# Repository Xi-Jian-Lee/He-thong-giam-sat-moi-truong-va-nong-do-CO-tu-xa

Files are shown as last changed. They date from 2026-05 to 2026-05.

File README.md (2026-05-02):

Tên đề tài: Nghiên cứu, thiết kế và phát triển hệ thống IoT giám sát môi trường và nồng độ CO từ xa dựa trên cảm biến nhiệt độ, khói và lửa.

Sơ lược đề tài: ESP32 thu thập dữ liệu từ cảm biến khói, lửa và nhiệt độ. ESP32 sẽ xử lý dữ liệu để hiện ra màn hình OLED và đồng thời gửi về giao diện người dùng, sử dụng ứng dụng Blynk IoT. Bên cạnh đó, ESP32 sẽ kích hoạt còi hoặc loa để cảnh báo các trường hợp đặc biệt.

Video giới thiệu vận hành sản phẩm: https://youtu.be/24HGrBEQO44

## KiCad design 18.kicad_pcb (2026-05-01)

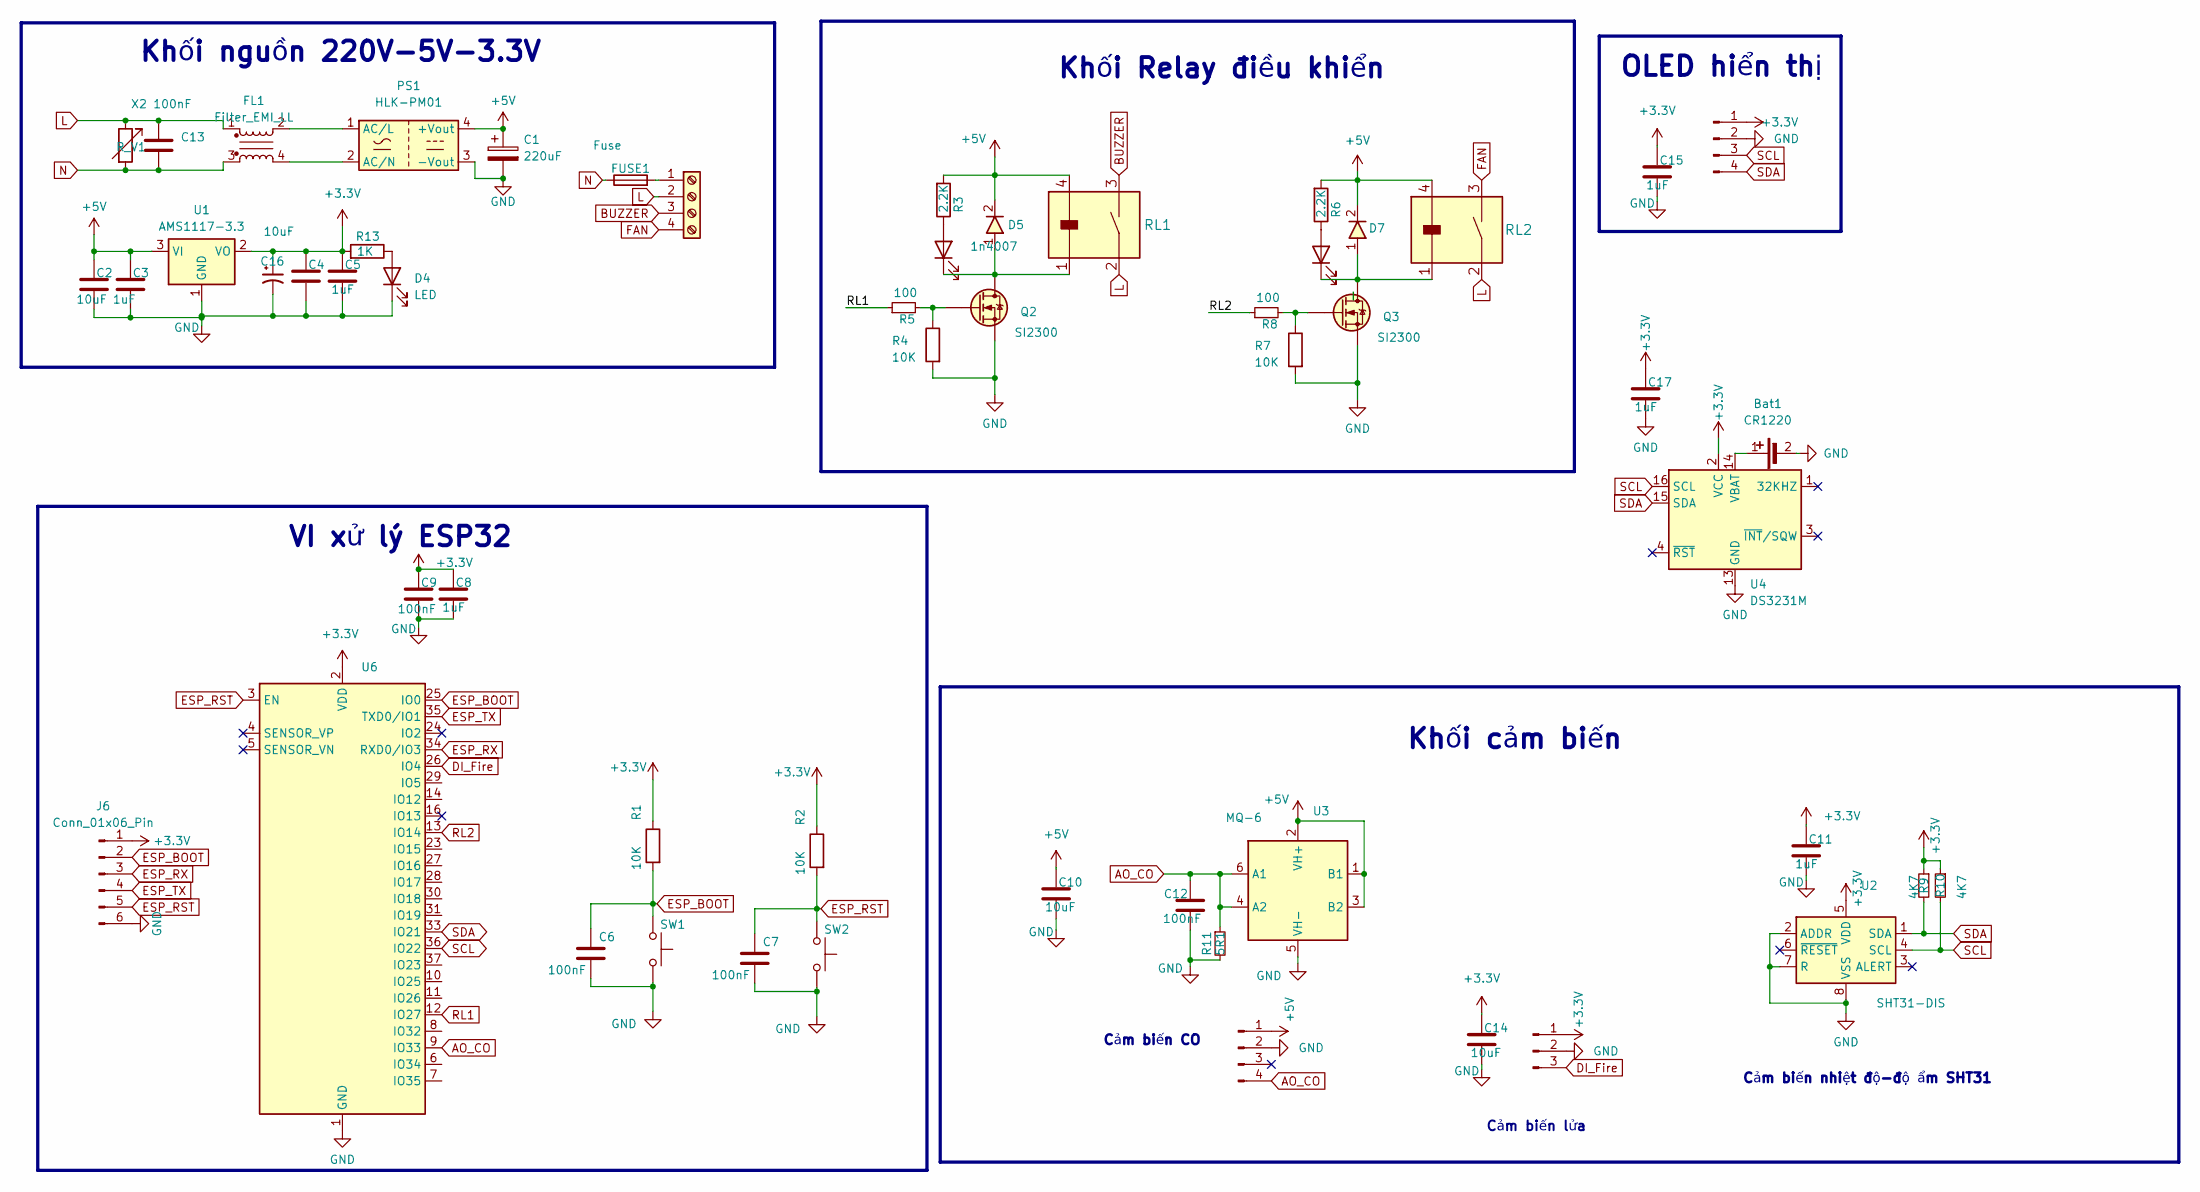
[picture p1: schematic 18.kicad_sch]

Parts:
Bat1: CR1220; BatteryHolder_CR1220
C1: 220uF; CP_Elec_8x10.5
C2, C4, C10, C14: 10uF; C_0603
C3, C5, C8, C11, C15, C17: 1uF; C_0603
C6, C7, C9, C12: 100nF; C_0603
C13: X2 100nF; C_Rect_L16.5mm_W6.0mm_P15.00mm_MKT
C16: C_Polarized_Small_US; Tantalum_1206
D1, D2: LED; LED_0603
D4: LED; LED_0603_1608Metric
D5, D7: 1n4007; D_SOD-123
FL1: Filter_EMI_LL; ACFilterChokeUU9.8
FUSE1: Fuse; Fuse_Bourns_MF-RG300
J1, J4: Conn_01x04_Pin; PinHeader_1x04_P2.54mm_Vertical
J2: Conn_01x03_Pin; PinHeader_1x03_P2.54mm_Vertical
J3: Screw_Terminal_01x04; TerminalBlock_Screw_HB9500_4P_P9.5mm
J6: Conn_01x06_Pin; PinHeader_1x06_P2.54mm_Vertical
PS1: HLK-PM01; Converter_ACDC_Hi-Link_HLK-PMxx
Q2, Q3: SI2300; SOT23-3
R1, R2, R4, R7: 10K; R_0603
R3, R6: 2.2K; R_0603
R5, R8: 100; R_0603
R9, R10: 4K7; R_0603
R11: 5R1; R_0603
R13: 1K; R_0603
RL1, RL2: Relay_G5NB-1A-E_DC5; Relay_G5NB-1A-E DC5
R_V1: 10D751K; RV_Disc_D12mm_W5.8mm_P7.5mm
SW1, SW2: SW_Push; SW_SPST_CK_RS282G05A3
U1: AMS1117-3.3; SOT-223-3_TabPin2
U2: SHT31-DIS; Sensirion_DFN-8-1EP_2.5x2.5mm_P0.5mm_EP1.1x1.7mm
U3: MQ-6
U4: DS3231M; SOIC-16W_7.5x10.3mm_P1.27mm
U6: ESP32-WROOM-32E

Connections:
+3.3V: C4.1, C5.1, C8.1, C9.1, C11.1, C14.1, C15.1, C16.1, C17.1, J2.1, J4.1, J6.1, R1.1, R2.1, R9.1, R10.1, R13.2, U1.2 (VO), U2.5 (VDD), U4.2 (VCC), U6.2 (VDD)
+5V: C1.1, C2.1, C3.1, C10.1, D5.2, D7.2, J1.1, PS1.4 (+Vout), R3.2, R6.2, RL1.4, RL2.4, U1.3 (VI), U3.1 (B1), U3.2 (VH+), U3.3 (B2)
AO_CO: C12.1, J1.4, R11.1, U3.4 (A2), U3.6 (A1), U6.9 (IO33)
BUZZER: J3.3, RL1.3
DI_Fire: J2.3, U6.26 (IO4)
ESP_BOOT: C6.1, J6.2, R1.2, SW1.2, U6.25 (IO0)
ESP_RST: C7.1, J6.5, R2.2, SW2.2, U6.3 (EN)
ESP_RX: J6.3, U6.34 (RXD0/IO3)
ESP_TX: J6.4, U6.35 (TXD0/IO1)
FAN: J3.4, RL2.3
GND: Bat1.2 (-), C1.2, C2.2, C3.2, C4.2, C5.2, C6.2, C7.2, C8.2, C9.2, C10.2, C11.2, C12.2, C14.2, C15.2, C16.2, C17.2, D4.2 (K), J1.2, J2.2, J4.2, J6.6, PS1.3 (-Vout), Q2.2 (S), Q3.2 (S), R4.2, R7.2, R11.2, SW1.1, SW2.1, U1.1 (GND), U2.2 (ADDR), U2.7 (R), U2.8 (VSS), U2.9 (VSS), U3.5 (VH-), U4.5 (GND), U4.6 (GND), U4.7 (GND), U4.8 (GND), U4.9 (GND), U4.10 (GND), U4.11 (GND), U4.12 (GND), U4.13 (GND), U6.1 (GND), U6.15 (GND), U6.38 (GND), U6.39 (GND)
L: C13.1, FL1.1, J3.2, RL1.2, RL2.2, R_V1.1
N: C13.2, FL1.3, FUSE1.1, R_V1.2
unnamed: Bat1.1 (+), U4.14 (VBAT)
unnamed: D1.1 (A), R3.1
unnamed: D1.2 (K), D5.1, Q2.3 (D), RL1.1
unnamed: D2.1 (A), R6.1
unnamed: D2.2 (K), D7.1, Q3.3 (D), RL2.1
unnamed: D4.1 (A), R13.1
unnamed: FUSE1.2, J3.1
unnamed: FL1.2, PS1.1 (AC/L)
unnamed: FL1.4, PS1.2 (AC/N)
unnamed: Q2.1 (G), R4.1, R5.2
unnamed: Q3.1 (G), R7.1, R8.2
RL1: R5.1, U6.12 (IO27)
RL2: R8.1, U6.13 (IO14)
SCL: J4.3, R10.2, U2.4 (SCL), U4.16 (SCL), U6.36 (IO22)
SDA: J4.4, R9.2, U2.1 (SDA), U4.15 (SDA), U6.33 (IO21)

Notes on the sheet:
Khối cảm biến
OLED hiển thị
VI xử lý ESP32
Cảm biến nhiệt độ-độ ẩm SHT31
Khối Relay điều khiển
Khối nguồn 220V-5V-3.3V
Cảm biến CO
Cảm biến lửa

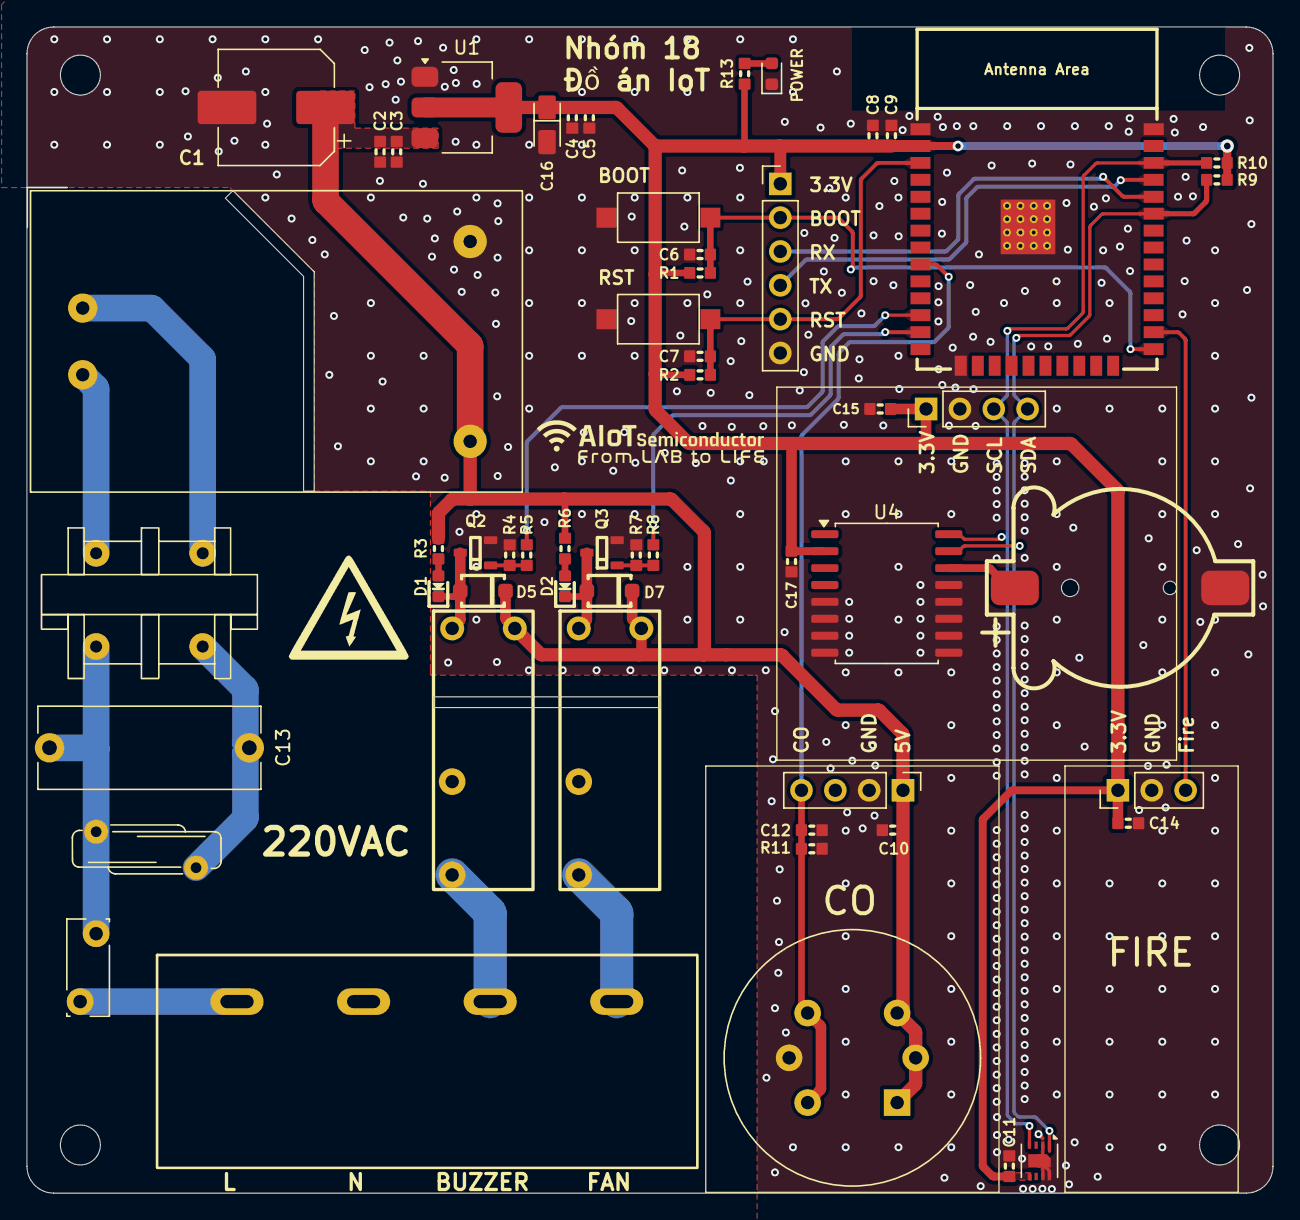
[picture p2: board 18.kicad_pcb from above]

Board: 2 copper layers, 93.5 x 87.5 mm, 55 parts (0 on the bottom side), 28 nets.

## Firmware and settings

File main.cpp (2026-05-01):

#include "main.h"

SystemMain::SystemMain()
  : fireSensor(4),// cảm biến lửa là chân 4
    gasSensor(33, 1860),// cảm biến gass là chân 33 ngưỡng bao động là 1860
    shtSensor(21, 22, 0x44),//Cảm biến nhiệt độ SHT31 dùng I2C (21, 22
    oledDisplay(21, 22, 0x3C, 128, 64, -1),//21 là chân SDA 22 là chân SCL , 0x3c địa chỉ IC2 của màn hình , 128 là chiều rộng màn hình 128pixel, 64 là chiều cao màn hình (64 pixel)
    relay(27, 14),//Còi/Quạt nối chân 27 và 14
     _wifi("HTN2", "LIENMINH"),// tên wifi và pass
   

   
    //_wifi("MrGonf", "1234567890"),// tên wifi và pass nhớ đổi khi cần wifi khác
    // nhớ đổi pass và tên trong app.h dòng 18 19

    app(),
    rtc(21, 22) {
}

bool SystemMain::begin() {
  Serial.begin(115200);
  Wire.begin(21, 22);
  oledDisplay.begin();
  vTaskDelay(pdMS_TO_TICKS(200));
  oledDisplay.initSys();
  shtSensor.begin();
  vTaskDelay(pdMS_TO_TICKS(200));
  rtc.begin();
  vTaskDelay(pdMS_TO_TICKS(200));
  gasSensor.begin();
  fireSensor.begin();
  relay.begin();
  vTaskDelay(pdMS_TO_TICKS(200));
  _wifi.connect();
  vTaskDelay(pdMS_TO_TICKS(500));
  app.begin();
  vTaskDelay(pdMS_TO_TICKS(200));

  xTaskCreatePinnedToCore(
    TaskFire,           // Hàm xử lý chính của task
    "FireSensor",       // Tên task
    2048,               // Stack size (bytes)
    this,               // Tham số truyền vào task
    2,                  // Priority
    &Task_Fire_Sensor,  // Handle của task
    1                   // Core ID
  );
  xTaskCreatePinnedToCore(TaskGas, "GasSensor", 2048, this, 2, &Task_Gas_Sensor, 1);
  xTaskCreatePinnedToCore(TaskSHT, "SHTSensor", 3072, this, 2, &Task_SHT31_Sensor, 1);
  xTaskCreatePinnedToCore(TaskOLED, "OLED", 4096, this, 1, &Task_OLED_Display, 1);
  xTaskCreatePinnedToCore(TaskRelay, "RELAY", 1024, this, 2, &Task_Relay, 1);
  xTaskCreatePinnedToCore(TaskWiFi, "_WiFi", 4096, this, 2, &Task_WiFi, 0);
  xTaskCreatePinnedToCore(TaskApp, "APP", 4096, this, 2, &Task_App, 0);
  xTaskCreatePinnedToCore(TaskRTC, "RTC", 4096, this, 2, &Task_RTC, 1);

  return true;
}

void SystemMain::wifiStatus() {
  if (_wifi.isConnected()) {
    oledDisplay.displayStatus(_wifi.signalQuality());
  } else {
    oledDisplay.connectWifi();
  }
}

//============================== TaskRTC =======================================//
void SystemMain::TaskRTC(void *pvParameters) {
  SystemMain *sys = (SystemMain *)pvParameters;
  for (;;) {// vòng lập vô tận luôn cập nhật trạng thái 
    // sys->rtc.print_current_time();
    vTaskDelay(pdMS_TO_TICKS(500));
  }
}

//============================== TaskApp =======================================//
void SystemMain::TaskApp(void *pvParameters) {
  SystemMain *sys = (SystemMain *)pvParameters;
  for (;;) {
    sys->app.update();// duy trì kết nối vs sever
    sys->app.updateSensor(sys->temperature, sys->humidity, sys->gasValue, sys->fireDetected);//Đẩy các thông số Nhiệt độ, Độ ẩm, Gas, và Lửa lên App để bạn có thể xem từ xa.
    vTaskDelay(pdMS_TO_TICKS(500));// tầ suất 0.5 s 1 lần
  }
}

//============================== TaskRelay =======================================//
void SystemMain::TaskRelay(void *pvParameters) {
  SystemMain *sys = (SystemMain *)pvParameters;
  static uint32_t manualStart = 0;
  const uint32_t MANUAL_TIMEOUT = 15UL * 1000UL;  // 5UL * 60UL * 1000UL
  for (;;) {
    bool danger = (sys->gasDetected || sys->fireDetected || sys->temperature > 42); // nếu nhiệt độ lớn hơn 42 thì báo cháy, phát hiện rò gas và lửa
    if (modeState == MODE_AUTO) {
      Serial.println("modeState == AUTO");
      if (danger) {
        sys->relay.isOn();
      } else if (!danger) {
        sys->relay.isOff();
      }
      manualStart = 0;
    } else {

      Serial.println("modeState == MANUAL");// chế độ thù công sau 15s ko tương tác sẽ tính toán lại cho an toàn
      if (manualStart == 0) {
        manualStart = millis();
      } else if (millis() - manualStart > MANUAL_TIMEOUT) {
        manualStart = 0;
        // modeState = MODE_AUTO;
        sys->app.setLastSentMode();
        Serial.println("[RELAY] Auto-revert to AUTO");
      }
    }

    // sys->wifiQuality = sys->_wifi.signalQuality();

    vTaskDelay(pdMS_TO_TICKS(500));
  }
}

//============================== TaskWiFi =======================================//
void SystemMain::TaskWiFi(void *pvParameters) {
  SystemMain *sys = (SystemMain *)pvParameters;
  for (;;) {
    sys->wifiStrength = sys->_wifi.signalStrength();// liên tục lấy giá trị từ router tính bằng dBm
    // sys->wifiQuality = sys->_wifi.signalQuality();

    vTaskDelay(pdMS_TO_TICKS(500));
  }
}

//============================== TaskFire =======================================//
void SystemMain::TaskFire(void *pvParameters) {
  SystemMain *sys = (SystemMain *)pvParameters;
  for (;;) {
    sys->fireDetected = sys->fireSensor.read();// đọc xem có lửa ko
    vTaskDelay(pdMS_TO_TICKS(500));// chạy liên tục cập nhật mổi 0,5s
  }
}
//============================== TaskGas =======================================//
void SystemMain::TaskGas(void *pvParameters) {
  SystemMain *sys = (SystemMain *)pvParameters;
  for (;;) {
    sys->gasValue = sys->gasSensor.readRaw();// đọc giá trị gas
    sys->gasDetected = sys->gasSensor.isGasDetected();// so sánh xem an toàn hay không

    // int raw = sys->gasSensor.readRaw();
    // Serial.print("Gas Value: ");
    // Serial.println(raw);
    // if (sys->gasSensor.isGasDetected())
    // {
    //     Serial.println("Gas detected!");
    // }
    vTaskDelay(pdMS_TO_TICKS(500));
  }
}
//============================== TaskSHT =======================================//
void SystemMain::TaskSHT(void *pvParameters) {
  SystemMain *sys = (SystemMain *)pvParameters;
  for (;;) {
    sys->temperature = sys->shtSensor.readTemperature();
    sys->humidity = sys->shtSensor.readHumidity();
    vTaskDelay(pdMS_TO_TICKS(1000));// giám sát độ ẩm nhưng ko dùng độ ẩm để kích hoạt báo động
  }
}
//============================== TaskOLED ========================================// úp dữ liệu lên oled
void SystemMain::TaskOLED(void *pvParameters) {
  SystemMain *sys = (SystemMain *)pvParameters;

  char buffer[128];

  for (;;) {
    sys->oledDisplay.clear();// xóa sạch bộ nhớ đệm
    sys->oledDisplay.Template();// vẽ lại các nhãn tính nhiệt độm độ ẩm, gas
    // --- Nhiệt độ ---
    snprintf(buffer, sizeof(buffer), "%.1f C", sys->temperature);
    sys->oledDisplay.printText(buffer, 30, 15, 1);// ghi vào tọa độ xác định

    // --- Độ ẩm ---
    snprintf(buffer, sizeof(buffer), "%.1f %%", sys->humidity);
    sys->oledDisplay.printText(buffer, 30, 25, 1);

    // --- Gas ---
    snprintf(buffer, sizeof(buffer), "%d ppm", sys->gasValue);
    sys->oledDisplay.printText(buffer, 30, 35, 1);

    // --- Fire ---
    snprintf(buffer, sizeof(buffer), "%s", sys->fireDetected ? "YES" : "NO");
    sys->oledDisplay.printText(buffer, 30, 45, 1);



    // --- RTC thời gian ---
    DateTime t = sys->rtc.now();
    snprintf(buffer, sizeof(buffer), "%04d-%02d-%02d|%02d:%02d", t.year(), t.month(), t.day(), t.hour(), t.minute());
    sys->oledDisplay.printText(buffer, 30, 55, 1);

    // --- Wifi ---
    sys->wifiStatus();
    // Cập nhật màn hình OLED
    sys->oledDisplay.update();// chốt hạ cập nhật

    vTaskDelay(pdMS_TO_TICKS(100));
  }
}

//Người sản xuất: TaskFire, TaskGas, TaskSHT đọc dữ liệu từ cảm biến rồi cất vào các biến chung (sys->temperature, sys->gasDetected,...).

//Người điều phối: TaskRelay nhìn vào các biến đó để quyết định bật hay tắt còi.

//Người báo cáo: TaskOLED và TaskApp lấy dữ liệu đó hiển thị cho người dùng xem.

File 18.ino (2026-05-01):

// #include "_WiFi.h"

// _WiFi _wifi("Thanh An", "linhtuyen78");
#include "main.h"
SystemMain sysMain;// Khởi tạo một đối tượng tên là sysMain. Mọi logic phức tạp về cảm biến khói, lửa, nhiệt độ và Blynk mà bạn mô tả đều được "gói" gọn bên trong đối tượng này
void setup()
{
  Serial.begin(115200);
  // _wifi.connect();
  // Serial.println(_wifi.signalStrength());
  sysMain.begin();//Đây là lệnh quan trọng nhất. Nó sẽ kích hoạt các lệnh khởi tạo bên trong file main.cpp
}

void loop()
{
  // if (!_wifi.isConnected()) {
  //   Serial.println("WiFi mất kết nối – đang thử lại...");
  //   _wifi.connect();
  // }
  // Serial.printf("Tín hiệu: %d%% - %s\n",
  //               _wifi.signalStrength(),
  //               _wifi.signalQuality().c_str());
  // delay(1000);




  // tên file có đuôi .cpp là file chứa lệnh thực thi của các hàm được liệt kê trong file đuôi .h còn file đuôi .h chứa các hàm nhưng ko chứa lệnh thực thi trong đó
  // code này sẽ chạy file main.h
}

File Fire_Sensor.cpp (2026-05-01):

#include "Fire_Sensor.h"

Fire_Sensor::Fire_Sensor(uint8_t gpio) : pin(gpio) {}//Khi bạn khai báo một cảm biến lửa mới, bạn truyền số chân (GPIO) mà bạn đã cắm cảm biến đó vào.

bool Fire_Sensor::begin()
{
    pinMode(pin, INPUT_PULLUP);//Thiết lập chân này là đầu vào (INPUT). Chế độ PULLUP sẽ kích hoạt một điện trở treo nội bộ bên trong chip ESP32
    //Giữ cho tín hiệu luôn ở mức cao (High) khi không có lửa, giúp tránh nhiễu tín hiệu điện khi dây dẫn dài hoặc môi trường có từ trường
    return true;
}

bool Fire_Sensor::read()
{
    return !digitalRead(pin);
    //Do các cảm biến lửa thông dụng trên thị trường thường trả về mức THẤP (0) khi phát hiện có lửa và mức CAO (1) khi bình thường
    // Nếu phát hiện lửa (0) trả về 1
}

bool Fire_Sensor::isFire()
{
    return read();//có lữa trả về true isFire tra ve true
}

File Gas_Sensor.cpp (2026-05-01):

#include "esp32-hal-adc.h"
#include "esp32-hal-gpio.h"
#include "Gas_Sensor.h"

Gas_Sensor::Gas_Sensor(uint8_t gpio, int threshold)//Tham số gpio: Chân cắm trên ESP32 (phải là chân có chức năng ADC - chuyển đổi tương tự sang số).
    : pin(gpio), thresholdLevel(threshold) {}//Tham số threshold: Ngưỡng nồng độ (ví dụ: 1000). Nếu nồng độ gas vượt quá con số này, hệ thống sẽ coi là có rò rỉ khí hoặc có khói.

bool Gas_Sensor::begin()
{
    pinMode(pin, INPUT_PULLUP);
    return true;
}

int Gas_Sensor::readRaw()
{// Đây là lệnh quan trọng nhất. Nó đọc điện áp từ cảm biến (từ 0V đến 3.3V) và chuyển thành một con số trong khoảng 0 đến 4095 
    return analogRead(pin);
}

bool Gas_Sensor::isGasDetected()
{//Hàm này lấy giá trị nồng độ hiện tại (value) đem so sánh với mức ngưỡng (thresholdLevel) mà bạn đã cài đặt ở hàm khởi tạo.
    int value = readRaw();
    return (value > thresholdLevel);
    // return readRaw();
}
   

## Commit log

2026-05-01 Mạch hệ thống
    [18.kicad_pcb, 18.kicad_sch]
2026-05-01 Giới thiệu.md

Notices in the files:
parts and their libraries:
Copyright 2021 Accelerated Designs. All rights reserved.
